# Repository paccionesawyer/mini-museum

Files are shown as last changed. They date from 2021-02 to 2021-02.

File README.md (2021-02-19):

# Mini - Museum

A voice activated rotating museum. While the options are admittedly limited, this mini museum boasts two of the most famous paintings in the world, printed on the finest white printer paper. Simply ask to see one of the two paintings, either the Mona Lisa or The Scream. One raspberry pi, the client, will take input from a microphone, parse that into text and look for a related keyword. Once it recognizes a keyword related to either painting, it will send a request to the IP Address of a second Raspberry Pi, the server, that describes which painting was mentioned. The server pi will take that information and turn a planetary gear system either 90 degrees to the right or left to display one painting on the front window and then return.

Demonstration of Functionality

[Full Video](https://youtu.be/GzdikGhd4Ek)
## Getting Started

These instructions will get you a copy of the project up and running on your local machine for development and testing purposes.

### Prerequisites

- Client Python Libraries
  - [Speech Recognition](https://pypi.org/project/SpeechRecognition/) (Used to recognize speech on client)
    - [pyaudio](https://pypi.org/project/PyAudio/) (Dependency of Speech Recognition)
  - [requests](https://pypi.org/project/requests/) (To Send Information to the Server Pi)
- Server Python Libraries
  - [RPi.GPIO](https://pypi.org/project/RPi.GPIO/) (To Communicate with Stepper Motor)
  - [Flask](https://pypi.org/project/Flask/) (To read requests from the Client Pi)
- Equipment 
  - [NEMA-17 Stepper Motor](https://www.adafruit.com/product/324) (Actuator)
    - Stepper Motor Driver
  - [Microphone](https://www.amazon.com/Lavalier-Microphone-Cardioid-Condenser-Computer/dp/B077VNGVL2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) (Sensor)
- [Raspberry Pi 4](https://www.google.com/search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) x2
- Breadboard power supply (Accepts power from a 2.1 x 5.5 mm plug from a 12 V wall adapter. Emits 12 V, 5 V, and 3.3 V at the same time.) Custom PCB

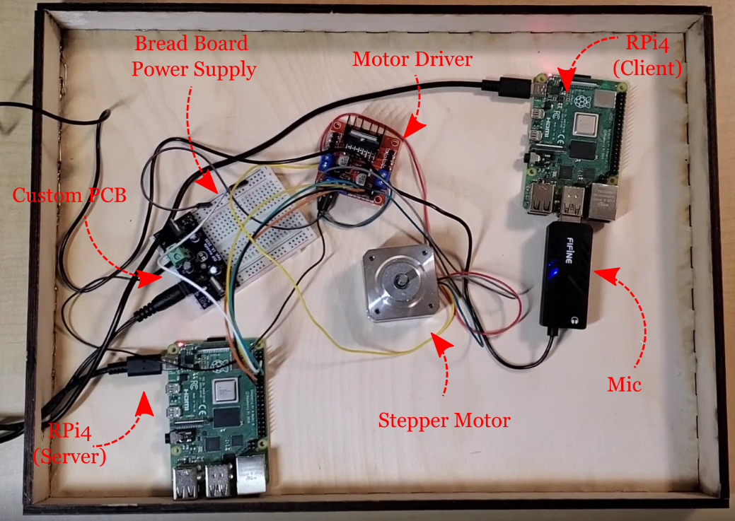
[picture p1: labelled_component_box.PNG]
Components


### Installing

Simply download the files in this repository and upload the client.py code to one Raspberry Pi attached to the microphone, and the server.py code to another Raspberry Pi attached to the Stepper Motor.

### Setup Notes

In our design there was a lower box that housed the electronics, the upper box housed the gears and paintings.

## Authors

- **Sawyer Bailey Paccione** - *Client Code and Gear Design* - [Portfolio](http://sawyerbaileypaccione.tech/)
- **Olif Hordofa** - *Server Code and Box Design* 

## License

This project is licensed under the MIT License - see the [LICENSE.md](LICENSE.md) file for details

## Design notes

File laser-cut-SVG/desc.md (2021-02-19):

Laser cut files ready to be cut on a 12''x24'' lasercutter.

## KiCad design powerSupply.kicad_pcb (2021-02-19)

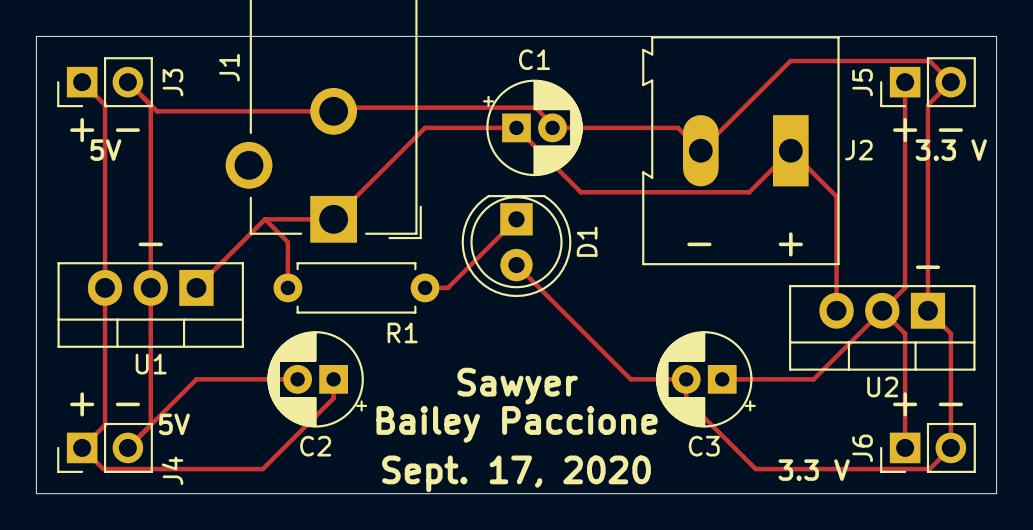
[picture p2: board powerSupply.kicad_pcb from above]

Board: 2 copper layers, 53.3 x 25.4 mm, 13 parts (0 on the bottom side), 5 nets.

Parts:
C1, C2, C3: 10 uF; CP_Radial_D5.0mm_P2.00mm
D1: LED; LED_D5.0mm
J1: Barrel_Jack_Switch; BarrelJack_CUI_PJ-102AH_Horizontal
J2: Screw_Terminal_01x02; TerminalBlock_Altech_AK300-2_P5.00mm
J3, J4, J5, J6: Conn_01x02_Male; PinHeader_1x02_P2.54mm_Vertical
R1: R; R_Axial_DIN0207_L6.3mm_D2.5mm_P7.62mm_Horizontal
U1: L7805; TO-220-3_Vertical
U2: LD1117S33TR_SOT223; TO-220-3_Vertical

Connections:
GND: C1.2, C2.2, C3.2, D1.2, J1.2, J2.2, J3.2, J4.2, J5.2, J6.2, U1.2, U2.1
unnamed: C1.1, J1.1, J2.1, R1.1, U1.1, U2.3
unnamed: C2.1, J3.1, J4.1, U1.3
unnamed: C3.1, J5.1, J6.1, U2.2
unnamed: D1.1, R1.2

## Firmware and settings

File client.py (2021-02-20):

"""
 Tufts University ME 30, Fall 2020
 client.py
 By:            Sawyer Bailey Paccione
 Completed:     12/8/2020
 Description:   Listens from the computer's default microphone, for the words
                in the global variable 'art', if they are heard, it will send
                information to the client to determine what it should do
 Purpose:       The client side code of Project 4 Art Installation
"""
import time # Used to wait after the user has been prompted

import speech_recognition as sr # Used to recognize speech

import pyaudio  # Dependency of Speech Recognition, also used to play audio
import wave
import sys
import requests

CHUNK = 1024

IP_ADDRESS = "PUT IP HERE"

def recognize_speech_from_mic(recognizer, microphone):
    """Transcribe speech from recorded from `microphone`.

    Returns a dictionary with three keys:
    "success": a boolean indicating whether or not the API request was
               successful
    "error":   `None` if no error occurred, otherwise a string containing
               an error message if the API could not be reached or
               speech was unrecognizable
    "transcription": `None` if speech could not be transcribed,
               otherwise a string containing the transcribed text
    """
    # check that recognizer and microphone arguments are appropriate type
    if not isinstance(recognizer, sr.Recognizer):
        raise TypeError("`recognizer` must be `Recognizer` instance")

    if not isinstance(microphone, sr.Microphone):
        raise TypeError("`microphone` must be `Microphone` instance")

    # adjust the recognizer sensitivity to ambient noise and record audio
    # from the microphone
    with microphone as source:
        recognizer.adjust_for_ambient_noise(source)
        audio = recognizer.listen(source)

    # set up the response object
    response = {
        "success": True,
        "error": None,
        "transcription": None

    # try recognizing the speech in the recording
    # if a RequestError or UnknownValueError exception is caught,
    #     update the response object accordingly
    try:
        response["transcription"] = recognizer.recognize_google(audio)
    except sr.RequestError:
        # API was unreachable or unresponsive
        response["success"] = False
        response["error"] = "API unavailable"
    except sr.UnknownValueError:
        # speech was unintelligible
        response["error"] = "Unable to recognize speech"

    return response

def search_keyword(audio):
    """
        Search the recorded speech for the name of a painting
        This information will then be sent to the client to be handled with
        appropriately
    """

    mona_lisa = ["mona", "lisa", "vinci", "leonardo"]
    the_scream = ["scream", "edvard", "munch", "screen"]

    for word in mona_lisa:
        if word.lower() in audio.lower():
            print("Mona Lisa \n")
            # send information for mona_lisa
            info = 'http://{ip}:5000/mona'.format(ip = IP_ADDRESS)
            reply = requests.get(info)

            print(info)
            return

    for word in the_scream:
        if word.lower() in audio.lower():
            print("The Scream \n")
            # send information for scream
            info = 'http://{ip}:5000/scream'.format(ip = IP_ADDRESS)
            reply = requests.get(info)
            print(info)
            return

    # send information for not recognizing
    print("Didn't Recognize That Painting")

def simulation_over(audio):
    if ("quit" in audio.lower()):
        return True


if __name__ == "__main__":
    # Constant
    PROMPT_LIMIT = 10

    # create recognizer and mic instances
    recognizer = sr.Recognizer()
    microphone = sr.Microphone()

    gameOver = False

    while (not gameOver):
        print('Speak! \n')
        for j in range(PROMPT_LIMIT):
            request = recognize_speech_from_mic(recognizer, microphone)
            if request["transcription"]:
                break
            if not request["success"]:
                break
            # Send Info For Try Again Maybe 4
            print("Sorry, Speak Again!")

        # show the user the transcription
        print("You said: {}".format(request["transcription"]))

        # determine if request is in the database
        search_keyword(request["transcription"])
        gameOver = simulation_over(request["transcription"])

    print("Thank You for playing \n")

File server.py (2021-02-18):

#Server code for ME 30 Project 4
#Olif Hordofa
#Dec 08, 2020

import RPi.GPIO as GPIO
from flask import Flask
import time

app = Flask(__name__)

#assign pins to be used
P_A1 = 11 
P_A2 = 12
P_B1 = 13
P_B2 = 15
delay = 0.01 # time to settle

#setup the pins into output
def setup():
    GPIO.setmode(GPIO.BOARD)
    GPIO.setup(P_A1, GPIO.OUT)
    GPIO.setup(P_A2, GPIO.OUT)
    GPIO.setup(P_B1, GPIO.OUT)
    GPIO.setup(P_B2, GPIO.OUT)

#move the motor clockwise
def forwardStep():
    setStepper(1, 0, 1, 0)
    setStepper(0, 1, 1, 0)
    setStepper(0, 1, 0, 1)
    setStepper(1, 0, 0, 1)

#move the motor counterclockwise
def backwardStep():
    setStepper(1, 0, 0, 1)
    setStepper(0, 1, 0, 1)
    setStepper(0, 1, 1, 0)
    setStepper(1, 0, 1, 0)

#controls excitation to fire up
def setStepper(in1, in2, in3, in4):
    GPIO.output(P_A1, in1)
    GPIO.output(P_A2, in2)
    GPIO.output(P_B1, in3)
    GPIO.output(P_B2, in4)
    time.sleep(delay)

setup()

#keyword "scream" comes in from the client (mic)
@app.route('/scream')
def scream():

    for i in range(67):
        forwardStep()

    time.sleep(5)

    for i in range(68):
        backwardStep()

    return "Hope it was fun!"

#keyword "mona" comes in from the client (mic)
@app.route('/mona')
def monalisa():

    for i in range(68):
        backwardStep()
    time.sleep(5)
    for i in range(67):
        forwardStep()
   
    return "Hope it was fun!"

GPIO.cleanup()
